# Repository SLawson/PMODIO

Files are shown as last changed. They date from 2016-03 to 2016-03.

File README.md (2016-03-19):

## PMODIO

#### Project Description
The PMODIO device is an IO expansion for use with the Digilent Nexys4DDR board. It has a 128x64 dot-matrix graphical display and a quadrature rotary encoder. It connects to to Nexys4DDR's expansion headers (JA & JB by default, but this can be configured).

This project contains a CadSoft EAGLE schematic and board layout, and bill of materials for constructing them from scratch. It also contains a Xilinx custom peripheral IP with drivers for interfacing with the board.

#### Repository Layout

	/doc
    	/datasheets						Third-party datasheets for all BOM components
        BOM.xlsx						Bill of materials
        PMODIO_DriverReference.pdf		PMODIO driver reference
        PMODIO_UserGuide.pdf			User guide for hardware and the peripheral
    /src
    	/doc							Documentation source files
        /function_test					Source code for a Vivado and Xilinx SDK project 
        								to verify breadboard/PCB functionality
                                        	- also provides driver usage examples
        /physical						Eagle schematic and board layout, solder stencil
        /PMODIO_1.0						Peripheral IP block
    /LICENSE							License description (GPL v3)
        
#### Repository Branches
 
| Branch Name 	|	Purpose 												|
|---|---|
| master	  	| release branch 											|
| rev1			| latest development for board revision 1.x					|
| dev			| development - will always correspond to latest board rev	|

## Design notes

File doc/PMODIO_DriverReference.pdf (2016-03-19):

## PMODIO

Generated by Doxygen 1.8.6

Fri Mar 18 2016 23:13:56

CONTENTS | 1

## Contents

1 Data Structure Index | 1
2 File Index | 2
3 Data Structure Documentation | 2
4 File Documentation | 3
Index | 25

## 1 Data Structure Index

Generated on Fri Mar 18 2016 23:13:56 for PMODIO by Doxygen

### 2 CONTENTS

### 1.1 Data Structures

Here are the data structures with brief descriptions:

LCD_pos | 2
PMODIO | 3

## 2 File Index

### 2.1 File List

Here is a list of all documented files with brief descriptions:

PMODIO.c | 3
PMODIO.h | 8
PMODIO_l.c | 14
PMODIO_l.h | 19

## 3 Data Structure Documentation

### 3.1 LCD_pos Struct Reference

#include <PMODIO.h>

Data Fields

- u8 x
- u8 y
- u8 page

### 3.1.1 Detailed Description

Tracks current LCD write position

### 3.1.2 Field Documentation

### 3.1.2.1 u8 LCD_pos::page

current page

### 3.1.2.2 u8 LCD_pos::x

current X coordinate

### 3.1.2.3 u8 LCD_pos::y

current Y coordinate

The documentation for this struct was generated from the following file:

- PMODIO.h

3.2 PMODIO Struct Reference | 3

### 3.2 PMODIO Struct Reference

#include <PMODIO.h>

Data Fields

- u32 base_addr
- LCD_pos current_pos
- u8 lcd_map [LCD_PAGES][LCD_COLS]

### 3.2.1 Detailed Description

One instance of this type must be instantiated for each instance of the PMODIO peripheral in the system

### 3.2.2 Field Documentation

### 3.2.2.1 u32 PMODIO::base_addr

device base address

### 3.2.2.2 LCD_pos PMODIO::current_pos

current LCD write position

### 3.2.2.3 u8 PMODIO::lcd_map[LCD_PAGES][LCD_COLS]

static array to track writes to LCD

The documentation for this struct was generated from the following file:

- PMODIO.h

## 4 File Documentation

### 4.1 PMODIO.c File Reference

#include "stdbool.h"

#include "xparameters.h"

#include "xil_types.h"

#include "xstatus.h"

#include "PMODIO.h"

#include "PMODIO_l.h"

Macros

- #define ROT_BTN_MSK 0x00000001
- #define ROT_CLR_SET_MSK 0x00000002
- #define ROT_CLR_CLR_MSK (ROT_CLR_SET_MSK ∧ 0xFFFFFFFF)
- #define SELF_TEST_REG_CNT 3
- #define SELF_TEST_PATTERN 0xF0F0F0F0

### 4 CONTENTS

Functions

- XStatus PMODIO_init (PMODIO ∗inst_p, u32 base_addr)
- XStatus PMODIO_selfTest (PMODIO ∗inst_p)
- XStatus PMODIO_ROT_setStep (PMODIO ∗inst_p, int step)
- XStatus PMODIO_ROT_setMaxCount (PMODIO ∗inst_p, int count)
- XStatus PMODIO_ROT_setMinCount (PMODIO ∗inst_p, int count)
- XStatus PMODIO_ROT_clr (PMODIO ∗inst_p)
- XStatus PMODIO_ROT_read (PMODIO ∗inst_p, int ∗rotary_cnt_p)
- bool PMODIO_ROT_isBtnPressed (PMODIO ∗inst_p)
- XStatus PMODIO_LCD_setPos (PMODIO ∗inst_p, u8 x, u8 y)
- LCD_pos PMODIO_LCD_getPos (PMODIO ∗inst_p)
- XStatus PMODIO_LCD_write (PMODIO ∗inst_p, u8 data, u8 mask)
- XStatus PMODIO_LCD_clr (PMODIO ∗inst_p)

### 4.1.1 Detailed Description

Author

Scott Lawson

Copyright

Scott Lawson, 2016

PMODIO peripheral driver API function implementations

The PMODIO peripheral interfaces with the PMODIO hardware, which consists of a KS0108-compatible 128 pixel x 64 pixel dot-matrix graphical LCD and a quadrature rotary encoder.

These functions allow an application to interface with the LCD and rotary encoder hardware to draw on the LCD and obtain the rotary encoder’s rotation count, and configure the rotary encoder’s step size per rotation, count limits, and rotation increment/decrement directions.

Note

The LCD code is derived from the GLCD library from microchip.com. Download link: http://www.-microchip.com/forums/download.axd?file=0;275906

Modification History:

Ver | Who | Date | Changes
1.0 | SRL | 16 Mar 2016 | Initial release

### 4.1.2 Macro Definition Documentation

4.1.2.1 #define ROT_BTN_MSK 0x00000001

rotary encoder pushbutton status

4.1.2.2 #define ROT_CLR_CLR_MSK (ROT_CLR_SET_MSK ∧ 0xFFFFFFFF)

clear count bit mask

4.1 PMODIO.c File Reference | 5

4.1.2.3 #define ROT_CLR_SET_MSK 0x00000002

set the clear count bit mask

4.1.2.4 #define SELF_TEST_PATTERN 0xF0F0F0F0

pattern written to registers and read back during self-test

4.1.2.5 #define SELF_TEST_REG_CNT 3

number of registers being tested

### 4.1.3 Function Documentation

### 4.1.3.1 XStatus PMODIO_init ( PMODIO ∗ inst_p, u32 base_addr )

Initializes the PMODIO peripheral

Configures rotary encoder defaults Count step is 1 Negative counts are allowed Max count of 2∧32

Parameters

inst_p | PMODIO instance address
base_addr | Base address of PMODIO instance

Returns

- XST_SUCCESS if all self-test code passed
- XST_FAILURE if any self-test code failed

Note

This must be the first function called for this peripheral
This function calls PMODIO_SelfTest(), so it’s notes apply for this function as well

### 4.1.3.2 XStatus PMODIO_LCD_clr ( PMODIO ∗ inst_p )

Clears all pixels on the LCD

Parameters

inst_p PMODIO instance address

Returns

XST_SUCESS

### 4.1.3.3 LCD_pos PMODIO_LCD_getPos ( PMODIO ∗ inst_p )

Retrieves the current LCD write position

Parameters

### 6 CONTENTS

inst_p PMODIO instance address

Returns

LCD_pos current write position of the LCD

### 4.1.3.4 XStatus PMODIO_LCD_setPos ( PMODIO ∗ inst_p, u8 x, u8 y )

Sets the X-Y position for the next data write

X coordinate valid range is 0 - 127, inclusive Y coordinate valid range is 0 - 63, inclusive

Parameters

inst_p | PMODIO instance address
x | x-coordinate
y | y-coordinate

Returns

- XST_SUCCESS if X and Y coordinates are in the valid range (x < 128 and Y < 64)
- XST_FAILURE if either coordinate is out of range

### 4.1.3.5 XStatus PMODIO_LCD_write ( PMODIO ∗ inst_p, u8 data, u8 mask )

Writes data to LCD at the current position

Parameters

inst_p | PMODIO instance address
data | data to write
mask | mask to select which bits are written

Returns

XST_SUCESS

Note

The PMODIO instance’s current X position will be automatically incremented by 1 on every write.
Since writes to the LCD must be done a full byte at a time, the mask argument is provided to prevent the caller from having to perform read-modify-write cycles when a data write overlaps with a previous write. The driver tracks all writes internally, and when writing new data, it handles the read-modify-write cyles to only write bits to the LCD that are enabled by a set bit in the mask.

### 4.1.3.6 XStatus PMODIO_ROT_clr ( PMODIO ∗ inst_p )

Resets the current count to zero

Parameters

inst_p PMODIO instance address

Returns

XST_SUCCESS

### 4.1.3.7 bool PMODIO_ROT_isBtnPressed ( PMODIO ∗ inst_p )

Returns the current state of the rotary encoder pushbutton

4.1 PMODIO.c File Reference | 7

Parameters

inst_p PMODIO instance address

Returns

true if the button is pressed, false otherwise

### 4.1.3.8 XStatus PMODIO_ROT_read ( PMODIO ∗ inst_p, int ∗ rotary_cnt_p )

Retrieves the current rotary encoder count

Parameters

inst_p | PMODIO instance address
rotary_cnt_p | pointer to the location to populate with the count

Returns

XST_SUCCESS

### 4.1.3.9 XStatus PMODIO_ROT_setMaxCount ( PMODIO ∗ inst_p, int count )

Sets the maximum count allowed

Parameters

inst_p | PMODIO instance address
count | the maximum allowed count

Returns

- XST_SUCCESS if max count input is valid (<= 2∧31 - 1)
- XST_FAILURE if count value is invalid

### 4.1.3.10 XStatus PMODIO_ROT_setMinCount ( PMODIO ∗ inst_p, int count )

Sets the minimum count allowed

Parameters

inst_p | PMODIO instance address
count | the maximum allowed count

Returns

- XST_SUCCESS if min count input is valid (>= -2∧31)
- XST_FAILURE if count value is invalid

### 4.1.3.11 XStatus PMODIO_ROT_setStep ( PMODIO ∗ inst_p, int step )

Sets the number that the rotary encoder count is incremented or decremented by per rotation

### 8 CONTENTS

Parameters

inst_p | PMODIO instance address
step | sets number of "counts" to increment or decrement the current count by when the ro-tary encoder is turned one click - can be negative to invert which rotation direction incre-ments/decrements the count

Returns

XST_SUCCESS

### 4.1.3.12 XStatus PMODIO_selfTest ( PMODIO ∗ inst_p )

Run a self-test on the driver/device

If the hardware system is not built correctly, this function may never return to the caller.

Parameters

inst_p PMODIO instance address

Returns

- XST_SUCCESS if all self-test code passed
- XST_FAILURE if any self-test code failed

Note

Caching must be turned off for this function to work
Self test may fail if data memory and device are not on the same bus

### 4.2 PMODIO.h File Reference

#include "stdbool.h"

Data Structures

- struct LCD_pos
- struct PMODIO

Macros

- #define ROT_CNT_ABS_MAX 2147483647
- #define ROT_CNT_ABS_MIN (-2147483648)
- #define LCD_X_MAX 127
- #define LCD_Y_MAX 63
- #define LCD_CHIP_ON 0x3F
- #define LCD_CHIP_OFF 0x3E
- #define LCD_DISP_START 0xC0
- #define LCD_COL_SET 0xB8
- #define LCD_ROW_SET 0x40
- #define LCD_COLS 128
- #define LCD_PAGES 8
- #define LCD_PAGE_HEIGHT 8

4.2 PMODIO.h File Reference | 9

Functions

- XStatus PMODIO_init (PMODIO ∗inst_p, u32 base_addr)
- XStatus PMODIO_selfTest (PMODIO ∗inst_p)
- XStatus PMODIO_ROT_setStep (PMODIO ∗inst_p, int step)
- XStatus PMODIO_ROT_setMaxCount (PMODIO ∗inst_p, int count)
- XStatus PMODIO_ROT_setMinCount (PMODIO ∗inst_p, int count)
- XStatus PMODIO_ROT_clr (PMODIO ∗inst_p)
- XStatus PMODIO_ROT_read (PMODIO ∗inst_p, int ∗rotary_cnt_p)
- bool PMODIO_ROT_isBtnPressed (PMODIO ∗inst_p)
- XStatus PMODIO_LCD_setPos (PMODIO ∗inst_p, u8 x, u8 y)
- XStatus PMODIO_LCD_write (PMODIO ∗inst_p, u8 data, u8 mask)
- XStatus PMODIO_LCD_clr (PMODIO ∗inst_p)
- LCD_pos PMODIO_LCD_getPos (PMODIO ∗inst_p)

### 4.2.1 Detailed Description

Author

Scott Lawson

Copyright

Scott Lawson, 2016

Header file for PMODIO driver API

Modification History:

Ver | Who | Date | Changes
1.0 | SRL | 16 Mar 2016 | Initial release

### 4.2.2 Macro Definition Documentation

4.2.2.1 #define LCD_CHIP_OFF 0x3E

LCD command bit pattern: chip off

4.2.2.2 #define LCD_CHIP_ON 0x3F

LCD command bit pattern: chip on

4.2.2.3 #define LCD_COL_SET 0xB8

LCD command bit pattern: column set

4.2.2.4 #define LCD_COLS 128

number of columns on the LCD

4.2.2.5 #define LCD_DISP_START 0xC0

LCD command bit pattern: display start

### 10 CONTENTS

4.2.2.6 #define LCD_PAGE_HEIGHT 8

pixel height of one page

4.2.2.7 #define LCD_PAGES 8

number of pages on the LCD

4.2.2.8 #define LCD_ROW_SET 0x40

LCD command bit pattern: row set

4.2.2.9 #define LCD_X_MAX 127

LCD maximum X coordinate

4.2.2.10 #define LCD_Y_MAX 63

LCD maximum y coordinate

4.2.2.11 #define ROT_CNT_ABS_MAX 2147483647

Rotary encoder absolute maximum count (2∧(32 - 1) - 1)

4.2.2.12 #define ROT_CNT_ABS_MIN (-2147483648)

Rotary encoder absolute minimum count (-2∧(32 - 1))

### 4.2.3 Function Documentation

### 4.2.3.1 XStatus PMODIO_init ( PMODIO ∗ inst_p, u32 base_addr )

Initializes the PMODIO peripheral

Configures rotary encoder defaults Count step is 1 Negative counts are allowed Max count of 2∧32

Parameters

inst_p | PMODIO instance address
base_addr | Base address of PMODIO instance

Returns

- XST_SUCCESS if all self-test code passed
- XST_FAILURE if any self-test code failed

Note

This must be the first function called for this peripheral
This function calls PMODIO_SelfTest(), so it’s notes apply for this function as well

### 4.2.3.2 XStatus PMODIO_LCD_clr ( PMODIO ∗ inst_p )

Clears all pixels on the LCD

4.2 PMODIO.h File Reference | 11

Parameters

inst_p PMODIO instance address

Returns

XST_SUCESS

### 4.2.3.3 LCD_pos PMODIO_LCD_getPos ( PMODIO ∗ inst_p )

Retrieves the current LCD write position

Parameters

inst_p PMODIO instance address

Returns

LCD_pos current write position of the LCD

### 4.2.3.4 XStatus PMODIO_LCD_setPos ( PMODIO ∗ inst_p, u8 x, u8 y )

Sets the X-Y position for the next data write

X coordinate valid range is 0 - 127, inclusive Y coordinate valid range is 0 - 63, inclusive

Parameters

inst_p | PMODIO instance address
x | x-coordinate
y | y-coordinate

Returns

- XST_SUCCESS if X and Y coordinates are in the valid range (x < 128 and Y < 64)
- XST_FAILURE if either coordinate is out of range

### 4.2.3.5 XStatus PMODIO_LCD_write ( PMODIO ∗ inst_p, u8 data, u8 mask )

Writes data to LCD at the current position

Parameters

inst_p | PMODIO instance address
data | data to write
mask | mask to select which bits are written

Returns

XST_SUCESS

Note

The PMODIO instance’s current X position will be automatically incremented by 1 on every write.
Since writes to the LCD must be done a full byte at a time, the mask argument is provided to prevent the caller from having to perform read-modify-write cycles when a data write overlaps with a previous write. The driver tracks all writes internally, and when writing new data, it handles the read-modify-write cyles to only write bits to the LCD that are enabled by a set bit in the mask.

### 12 CONTENTS

### 4.2.3.6 XStatus PMODIO_ROT_clr ( PMODIO ∗ inst_p )

Resets the current count to zero

4.2 PMODIO.h File Reference | 13

Parameters

inst_p PMODIO instance address

Returns

XST_SUCCESS

### 4.2.3.7 bool PMODIO_ROT_isBtnPressed ( PMODIO ∗ inst_p )

Returns the current state of the rotary encoder pushbutton

Parameters

inst_p PMODIO instance address

Returns

true if the button is pressed, false otherwise

### 4.2.3.8 XStatus PMODIO_ROT_read ( PMODIO ∗ inst_p, int ∗ rotary_cnt_p )

Retrieves the current rotary encoder count

Parameters

inst_p | PMODIO instance address
rotary_cnt_p | pointer to the location to populate with the count

Returns

XST_SUCCESS

### 4.2.3.9 XStatus PMODIO_ROT_setMaxCount ( PMODIO ∗ inst_p, int count )

Sets the maximum count allowed

Parameters

inst_p | PMODIO instance address
count | the maximum allowed count

Returns

- XST_SUCCESS if max count input is valid (<= 2∧31 - 1)
- XST_FAILURE if count value is invalid

### 4.2.3.10 XStatus PMODIO_ROT_setMinCount ( PMODIO ∗ inst_p, int count )

Sets the minimum count allowed

Parameters

### 14 CONTENTS

inst_p | PMODIO instance address
count | the maximum allowed count

Returns

- XST_SUCCESS if min count input is valid (>= -2∧31)
- XST_FAILURE if count value is invalid

### 4.2.3.11 XStatus PMODIO_ROT_setStep ( PMODIO ∗ inst_p, int step )

Sets the number that the rotary encoder count is incremented or decremented by per rotation

Parameters

inst_p | PMODIO instance address
step | sets number of "counts" to increment or decrement the current count by when the ro-tary encoder is turned one click - can be negative to invert which rotation direction incre-ments/decrements the count

Returns

XST_SUCCESS

### 4.2.3.12 XStatus PMODIO_selfTest ( PMODIO ∗ inst_p )

Run a self-test on the driver/device

If the hardware system is not built correctly, this function may never return to the caller.

Parameters

inst_p PMODIO instance address

Returns

- XST_SUCCESS if all self-test code passed
- XST_FAILURE if any self-test code failed

Note

Caching must be turned off for this function to work
Self test may fail if data memory and device are not on the same bus

### 4.3 PMODIO_l.c File Reference

#include "xil_types.h"

#include "xstatus.h"

#include "PMODIO.h"

#include "PMODIO_l.h"

4.3 PMODIO_l.c File Reference | 15

Macros

- #define LCD_SET_CNTL_RST_N 0x00000001
- #define LCD_SET_CNTL_EN_OP 0x00000002
- #define LCD_SET_CNTL_REG_SEL 0x00000004
- #define LCD_SET_CNTL_CS_1 0x00000008
- #define LCD_SET_CNTL_CS_2 0x00000010
- #define LCD_CLR_CNTL_RST_N (LCD_clear_CNTL_RST_N ∧ 0xFFFFFFFF)
- #define LCD_CLR_CNTL_EN_OP (LCD_clear_CNTL_EN_OP ∧ 0xFFFFFFFF)
- #define LCD_CLR_CNTL_REG_SEL (LCD_clear_CNTL_REG_SEL ∧ 0xFFFFFFFF)
- #define LCD_CLR_CNTL_CS_1 (LCD_clear_CNTL_CS_1 ∧ 0xFFFFFFFF)
- #define LCD_CLR_CNTL_CS_2 (LCD_SET_CNTL_CS_2 ∧ 0xFFFFFFFF)
- #define DELAY_LEN 600
- #define nop() __asm__ __volatile__ ("nop")

Functions

- XStatus PMODIO_LCD_init (PMODIO ∗inst_p)
- XStatus PMODIO_LCD_execCmd (PMODIO ∗inst_p, u8 cmd, LCD_CHIP chip)
- XStatus PMODIO_LCD_writeCommit (PMODIO ∗inst_p, u8 data)
- XStatus PMODIO_LCD_writeDataBits (PMODIO ∗inst_p, u8 pattern)
- XStatus PMODIO_LCD_clrCntlBit (PMODIO ∗inst_p, LCD_CNTL_BIT bit)
- XStatus PMODIO_LCD_setCntlBit (PMODIO ∗inst_p, LCD_CNTL_BIT bit)
- XStatus PMODIO_LCD_exec (PMODIO ∗inst_p)
- void PMODIO_LCD_delay ()

### 4.3.1 Detailed Description

Author

Scott Lawson

Copyright

Scott Lawson, 2016

Contains implementations of low-level driver functions. These functions are used by the driver API functions.

This code targets a KS0108-compatible, 128x64 pixel, graphical LCD. It supports the API functions to provide 8-bit pattern writing to arbitray positions on the LCD. For these LCDs, X is the long axis, and Y is the short axis. The display is split into Chip 1 for the left half, and Chip 2 for the right half. The display area is further split into eight rows of pixels (8 pixels tall each), called "pages."

Bit/Pin Mapping:

Abbreviation | Enum Name | Description
RST | RESET_N | Active-low reset
EN | EN_OP | Falling-edge triggered operation enable
RS | REG_SEL | Register select (0=instruction, 1=data)
CS1 | CS1 | Chip-select 1
CS2 | CS2 | Chip-select 2

### 16 CONTENTS

Implementation Note: For the current hardware revision, there weren’t enough pins available for every pin on the LCD interface, so the read/write pin was tied to ground, which sets it as write-only. Since we can’t read from the LCD memory, we can’t do read-write-modify cycles. This is a problem when the application layer wants to write new pixels in a page and column that already has some pixels, or perform a write that is spread across two pages. In both cases, previously written display data will be overwritten if the data byte is simply put on the data bus and written out.

This driver overcomes this limitation by maintaining its own 128-bit x 64-bit array to keep track of display data. Every write to the LCD is also reflected in this array, so read-modify-write cycles are performed using this array to avoid clobbering existing display data in the LCD. This array is maintained in the PMODIO structure that is allocated for each instance of the PMODIO peripheral in the Vivado block diagram (it’s the lcd_map attribute).

Warning

These functions are not intended to be used directly by any code except the PMODIO driver API functions. They may modify internal state or otherwise interfere with normal driver operation if called from the main application.

Note

This code is derived from the GLCD library from microchip.com. Download link: http://www.-microchip.com/forums/download.axd?file=0;275906

Modification History:

Ver | Who | Date | Changes
1.0 | SRL | 16 Mar 2016 | Initial release

### 4.3.2 Macro Definition Documentation

4.3.2.1 #define DELAY_LEN 600

sets number of iterations for nop() delay loop in PMODIO_LCD_exec

4.3.2.2 #define LCD_CLR_CNTL_CS_1 (LCD_clear_CNTL_CS_1 ∧ 0xFFFFFFFF)

LCD control pin clear mask: chip select 1

4.3.2.3 #define LCD_CLR_CNTL_CS_2 (LCD_SET_CNTL_CS_2 ∧ 0xFFFFFFFF)

LCD control pin clear mask: chip select 2

4.3.2.4 #define LCD_CLR_CNTL_EN_OP (LCD_clear_CNTL_EN_OP ∧ 0xFFFFFFFF)

LCD control pin clear mask: enable

4.3.2.5 #define LCD_CLR_CNTL_REG_SEL (LCD_clear_CNTL_REG_SEL ∧ 0xFFFFFFFF)

LCD control pin clear mask: register select

4.3.2.6 #define LCD_CLR_CNTL_RST_N (LCD_clear_CNTL_RST_N ∧ 0xFFFFFFFF)

LCD control pin clear mask: reset

4.3 PMODIO_l.c File Reference | 17

4.3.2.7 #define LCD_SET_CNTL_CS_1 0x00000008

LCD control pin set mask: chip select 1

4.3.2.8 #define LCD_SET_CNTL_CS_2 0x00000010

LCD control pin set mask: chip select 2

4.3.2.9 #define LCD_SET_CNTL_EN_OP 0x00000002

LCD control pin set mask: enable

4.3.2.10 #define LCD_SET_CNTL_REG_SEL 0x00000004

LCD control pin set mask: register select

4.3.2.11 #define LCD_SET_CNTL_RST_N 0x00000001

LCD control pin set mask: reset

4.3.2.12 #define nop( ) __asm__ __volatile__ ("nop")

Implements a Microblaze nop

Returns

NONE

Note

C-style signature: void nop()

### 4.3.3 Function Documentation

### 4.3.3.1 XStatus PMODIO_LCD_clrCntlBit ( PMODIO ∗ inst_p, LCD_CNTL_BIT bit )

Clears the specified LCD control bit without modifying others

Parameters

inst_p | PMODIO instance address
bit | bit to clear

Returns

XST_SUCCESS

### 4.3.3.2 void PMODIO_LCD_delay ( )

Executes a NOP loop to meet LCD timing requirements

Returns

NONE

### 4.3.3.3 XStatus PMODIO_LCD_exec ( PMODIO ∗ inst_p )

Instructs the LCD to act on the data/command on the data bus

The LCD uses the falling edge of the EN pin as an indicator that the data bus has data to be consumed. The RS pin indicates if the data bus contains an instruction (0) to be executed, or data (1) to be written to display ram. Delay no-op loops are used to meet the LCD timing requirements.

### 18 CONTENTS

Parameters

inst_p PMODIO instance address

Returns

XST_SUCCESS

### 4.3.3.4 XStatus PMODIO_LCD_execCmd ( PMODIO ∗ inst_p, u8 cmd, LCD_CHIP chip )

Writes a command to the specified LCD chip

Parameters

inst_p | PMODIO instance address
cmd | the command to execute
chip | the chip to execute the command for

Returns

XST_SUCCESS

Note

The LCD uses its 8-bit data bus both for data and for commands.

### 4.3.3.5 XStatus PMODIO_LCD_init ( PMODIO ∗ inst_p )

Initializes the LCD

Parameters

inst_p PMODIO instance address

Returns

XST_SUCCESS

### 4.3.3.6 XStatus PMODIO_LCD_setCntlBit ( PMODIO ∗ inst_p, LCD_CNTL_BIT bit )

Sets the specified LCD control bit without modifying others

Parameters

inst_p | PMODIO instance address
bit | bit to set

Returns

XST_SUCCESS

### 4.3.3.7 XStatus PMODIO_LCD_writeCommit ( PMODIO ∗ inst_p, u8 data )

Commits data to LCD display RAM and driver LCD map

4.4 PMODIO_l.h File Reference | 19

Parameters

inst_p | PMODIO instance address
data | data to write

Returns

XST_SUCESS

Note

The LCD’s current X position will be automatically incremented by 1 on every write.

### 4.3.3.8 XStatus PMODIO_LCD_writeDataBits ( PMODIO ∗ inst_p, u8 pattern )

Writes a specified pattern to the LCD data bus

Parameters

inst_p | PMODIO instance address
pattern | bit pattern to write to LCD data bus

Returns

XST_SUCCESS

Note

The LCD uses its 8-bit data bus both for data and for commands.

### 4.4 PMODIO_l.h File Reference

#include "PMODIO.h"

Macros

- #define ROT_CNT 0
- #define ROT_STEP 4
- #define ROT_STS 8
- #define ROT_MAX_CNT 12
- #define ROT_MIN_CNT 16
- #define ROT_RSVD0 20
- #define LCD_DATA 24
- #define LCD_CNTL 28
- #define LCD_RSVD0 32
- #define GP_RSVD0 36
- #define GP_RSVD1 40
- #define GP_RSVD2 44
- #define PMODIO_mWriteReg(BaseAddress, RegOffset, Data) Xil_Out32((BaseAddress) + (RegOffset), (u32)(Data))
- #define PMODIO_mReadReg(BaseAddress, RegOffset) Xil_In32((BaseAddress) + (RegOffset))

Typedefs

- typedef enum CNTL_BIT LCD_CNTL_BIT
- typedef enum CHIP LCD_CHIP

### 20 CONTENTS

Enumerations

- enum CNTL_BIT {
RESET_N, EN_OP, REG_SEL, CS1, CS2 }
- enum CHIP { CHIP1, CHIP2 }

Functions

- XStatus PMODIO_LCD_init (PMODIO ∗inst_p)
- XStatus PMODIO_LCD_execCmd (PMODIO ∗inst_p, u8 cmd, LCD_CHIP chip)
- XStatus PMODIO_LCD_writeDataBits (PMODIO ∗inst_p, u8 pattern)
- XStatus PMODIO_LCD_writeCommit (PMODIO ∗inst_p, u8 data)
- XStatus PMODIO_LCD_setCntlBit (PMODIO ∗inst_p, LCD_CNTL_BIT bit)
- XStatus PMODIO_LCD_clrCntlBit (PMODIO ∗inst_p, LCD_CNTL_BIT bit)
- XStatus PMODIO_LCD_exec (PMODIO ∗inst_p)
- void PMODIO_LCD_delay ()

### 4.4.1 Detailed Description

Author

Scott Lawson

Copyright

Scott Lawson, 2016

Header file for low-level driver functions in the PMODIO peripheral driver.

Warning

This file is only intended for PMODIO driver use, and should not be directly included by applications. Use PMODIO.h for API access.

Modification History:

Ver | Who | Date | Changes
1.0 | SRL | 16 Mar 2016 | Initial release

### 4.4.2 Macro Definition Documentation

4.4.2.1 #define GP_RSVD0 36

Register offset: General purpose reserved

4.4.2.2 #define GP_RSVD1 40

Register offset: General purpose reserved

4.4 PMODIO_l.h File Reference | 21

4.4.2.3 #define GP_RSVD2 44

Register offset: General purpose reserved

4.4.2.4 #define LCD_CNTL 28

Register offset: LCD control

4.4.2.5 #define LCD_DATA 24

Register offset: LCD data

4.4.2.6 #define LCD_RSVD0 32

Register offset: LCD reserved 0

4.4.2.7 #define PMODIO_mReadReg( BaseAddress, RegOffset ) Xil_In32((BaseAddress) + (RegOffset))

Read a value from a PMODIO register. A 32 bit read is performed. If the component is implemented in a smaller width, only the least significant data is read from the register. The most significant data will be read as 0.

Parameters

BaseAddress | is the base address of the PMODIO device.
RegOffset | is the register offset from the base to write to.

Returns

Data is the data from the register.

Note

C-style signature: u32 PMODIO_mReadReg(u32 BaseAddress, unsigned RegOffset)

4.4.2.8 #define PMODIO_mWriteReg( BaseAddress, RegOffset, Data ) Xil_Out32((BaseAddress) + (RegOffset), (u32)(Data))

Write a value to a PMODIO register. A 32 bit write is performed. If the component is implemented in a smaller width, only the least significant data is written.

Parameters

BaseAddress | is the base address of the PMODIOdevice.
RegOffset | is the register offset from the base to write to.
Data | is the data written to the register.

Returns

None.

Note

C-style signature: void PMODIO_mWriteReg(u32 BaseAddress, unsigned RegOffset, u32 Data)

4.4.2.9 #define ROT_CNT 0

Register offset: Rotary encoder count

4.4.2.10 #define ROT_MAX_CNT 12

Register offset: Rotary encoder maximum allowed count

### 22 CONTENTS

4.4.2.11 #define ROT_MIN_CNT 16

Register offset: Rotary encoder minimum allowed count

4.4.2.12 #define ROT_RSVD0 20

Register offset: Rotary encoder reserved 0

4.4.2.13 #define ROT_STEP 4

Register offset: Rotary encoder step size

4.4.2.14 #define ROT_STS 8

Register offset: Rotary encoder status

### 4.4.3 Typedef Documentation

### 4.4.3.1 typedef enum CHIP LCD_CHIP

Available LCD Chips

### 4.4.3.2 typedef enum CNTL_BIT LCD_CNTL_BIT

LCD Control Bits

### 4.4.4 Enumeration Type Documentation

### 4.4.4.1 enum CHIP

Available LCD Chips

Enumerator

CHIP1 Chip 1 (left)

CHIP2 Chip 2 (right)

### 4.4.4.2 enum CNTL_BIT

LCD Control Bits

Enumerator

RESET_N Active-low reset

EN_OP Falling edge triggered operation enable

REG_SEL Register select (0 = instruction, 1 = command)

CS1 Chip Select 1 (left)

CS2 Chip Select 2 (right)

### 4.4.5 Function Documentation

### 4.4.5.1 XStatus PMODIO_LCD_clrCntlBit ( PMODIO ∗ inst_p, LCD_CNTL_BIT bit )

Clears the specified LCD control bit without modifying others

4.4 PMODIO_l.h File Reference | 23

Parameters

inst_p | PMODIO instance address
bit | bit to clear

Returns

XST_SUCCESS

### 4.4.5.2 void PMODIO_LCD_delay ( )

Executes a NOP loop to meet LCD timing requirements

Returns

NONE

### 4.4.5.3 XStatus PMODIO_LCD_exec ( PMODIO ∗ inst_p )

Instructs the LCD to act on the data/command on the data bus

The LCD uses the falling edge of the EN pin as an indicator that the data bus has data to be consumed. The RS pin indicates if the data bus contains an instruction (0) to be executed, or data (1) to be written to display ram. Delay no-op loops are used to meet the LCD timing requirements.

Parameters

inst_p PMODIO instance address

Returns

XST_SUCCESS

### 4.4.5.4 XStatus PMODIO_LCD_execCmd ( PMODIO ∗ inst_p, u8 cmd, LCD_CHIP chip )

Writes a command to the specified LCD chip

Parameters

inst_p | PMODIO instance address
cmd | the command to execute
chip | the chip to execute the command for

Returns

XST_SUCCESS

Note

The LCD uses its 8-bit data bus both for data and for commands.

### 4.4.5.5 XStatus PMODIO_LCD_init ( PMODIO ∗ inst_p )

Initializes the LCD

### 24 CONTENTS

Parameters

inst_p PMODIO instance address

Returns

XST_SUCCESS

### 4.4.5.6 XStatus PMODIO_LCD_setCntlBit ( PMODIO ∗ inst_p, LCD_CNTL_BIT bit )

Sets the specified LCD control bit without modifying others

Parameters

inst_p | PMODIO instance address
bit | bit to set

Returns

XST_SUCCESS

### 4.4.5.7 XStatus PMODIO_LCD_writeCommit ( PMODIO ∗ inst_p, u8 data )

Commits data to LCD display RAM and driver LCD map

Parameters

inst_p | PMODIO instance address
data | data to write

Returns

XST_SUCESS

Note

The LCD’s current X position will be automatically incremented by 1 on every write.

### 4.4.5.8 XStatus PMODIO_LCD_writeDataBits ( PMODIO ∗ inst_p, u8 pattern )

Writes a specified pattern to the LCD data bus

Parameters

inst_p | PMODIO instance address
pattern | bit pattern to write to LCD data bus

Returns

XST_SUCCESS

Note

The LCD uses its 8-bit data bus both for data and for commands.

## Index

base_addr
PMODIO,
3

CHIP1
PMODIO_l.h, 22
CHIP2
PMODIO_l.h, 22
CS1
PMODIO_l.h, 22
CS2
PMODIO_l.h, 22
CHIP
PMODIO_l.h, 22
CNTL_BIT
PMODIO_l.h, 22
current_pos
PMODIO,
3

DELAY_LEN
PMODIO_l.c, 16

EN_OP
PMODIO_l.h, 22

GP_RSVD0
PMODIO_l.h, 20
GP_RSVD1
PMODIO_l.h, 20
GP_RSVD2
PMODIO_l.h, 20

LCD_CHIP
PMODIO_l.h, 22
LCD_CHIP_OFF
PMODIO.h,
9
LCD_CHIP_ON
PMODIO.h,
9
LCD_CNTL
PMODIO_l.h, 21
LCD_CNTL_BIT
PMODIO_l.h, 22
LCD_COL_SET
PMODIO.h,
9
LCD_COLS
PMODIO.h,
9
LCD_DATA
PMODIO_l.h, 21
LCD_DISP_START
PMODIO.h,
9
LCD_PAGE_HEIGHT
PMODIO.h,
9
LCD_PAGES
PMODIO.h, 10
LCD_ROW_SET
PMODIO.h, 10
LCD_RSVD0

PMODIO_l.h, 21
LCD_X_MAX
PMODIO.h, 10
LCD_Y_MAX
PMODIO.h, 10
LCD_pos,
2
page,

2
x,

2
y,

2
lcd_map
PMODIO,
3

nop
PMODIO_l.c, 17

PMODIO_l.h
CHIP1, 22
CHIP2, 22
CS1, 22
CS2, 22
EN_OP, 22
REG_SEL, 22
RESET_N, 22
PMODIO,
3
base_addr,
3
current_pos,

3
lcd_map,
3
PMODIO.c,
3
PMODIO_LCD_clr,
5
PMODIO_LCD_getPos,
5
PMODIO_LCD_setPos,
6
PMODIO_LCD_write,
6
PMODIO_ROT_clr,
6
PMODIO_ROT_isBtnPressed,
6
PMODIO_ROT_read,
7
PMODIO_ROT_setMaxCount,
7
PMODIO_ROT_setMinCount,
7
PMODIO_ROT_setStep,
7
PMODIO_init,
5
PMODIO_selfTest,
8
ROT_BTN_MSK,
4
PMODIO.h,
8
LCD_CHIP_OFF,
9
LCD_CHIP_ON,
9
LCD_COL_SET,
9
LCD_COLS,
9
LCD_DISP_START,
9
LCD_PAGES, 10
LCD_ROW_SET, 10
LCD_X_MAX, 10
LCD_Y_MAX, 10
PMODIO_LCD_clr, 10
PMODIO_LCD_getPos, 11
PMODIO_LCD_setPos, 11
PMODIO_LCD_write, 11
PMODIO_ROT_clr, 11

### 26 INDEX

PMODIO_ROT_isBtnPressed, 13
PMODIO_ROT_read, 13
PMODIO_ROT_setMaxCount, 13 PMODIO_ROT_setMinCount, 13 PMODIO_ROT_setStep, 14
PMODIO_init, 10
PMODIO_selfTest, 14
PMODIO_LCD_clr
PMODIO.c, 5
PMODIO.h, 10
PMODIO_LCD_clrCntlBit
PMODIO_l.c, 17
PMODIO_l.h, 22
PMODIO_LCD_delay
PMODIO_l.c, 17
PMODIO_l.h, 23
PMODIO_LCD_exec
PMODIO_l.c, 17
PMODIO_l.h, 23
PMODIO_LCD_execCmd
PMODIO_l.c, 18
PMODIO_l.h, 23
PMODIO_LCD_getPos
PMODIO.c, 5
PMODIO.h, 11
PMODIO_LCD_init
PMODIO_l.c, 18
PMODIO_l.h, 23
PMODIO_LCD_setCntlBit
PMODIO_l.c, 18
PMODIO_l.h, 24
PMODIO_LCD_setPos
PMODIO.c, 6
PMODIO.h, 11
PMODIO_LCD_write
PMODIO.c, 6
PMODIO.h, 11
PMODIO_LCD_writeCommit
PMODIO_l.c, 18
PMODIO_l.h, 24
PMODIO_LCD_writeDataBits
PMODIO_l.c, 19
PMODIO_l.h, 24
PMODIO_ROT_clr
PMODIO.c, 6
PMODIO.h, 11
PMODIO_ROT_isBtnPressed
PMODIO.c, 6
PMODIO.h, 13
PMODIO_ROT_read
PMODIO.c, 7
PMODIO.h, 13
PMODIO_ROT_setMaxCount
PMODIO.c, 7
PMODIO.h, 13
PMODIO_ROT_setMinCount
PMODIO.c, 7
PMODIO.h, 13

PMODIO_ROT_setStep
PMODIO.c, 7
PMODIO.h, 14
PMODIO_init
PMODIO.c, 5
PMODIO.h, 10
PMODIO_l.c, 14
DELAY_LEN, 16
nop, 17
PMODIO_LCD_delay, 17
PMODIO_LCD_exec, 17
PMODIO_LCD_execCmd, 18
PMODIO_LCD_init, 18
PMODIO_LCD_writeCommit, 18 PMODIO_l.h, 19
CHIP, 22
CNTL_BIT, 22
GP_RSVD0, 20
GP_RSVD1, 20
GP_RSVD2, 20
LCD_CHIP, 22
LCD_CNTL, 21
LCD_CNTL_BIT, 22
LCD_DATA, 21
LCD_RSVD0, 21
PMODIO_LCD_delay, 23
PMODIO_LCD_exec, 23
PMODIO_LCD_execCmd, 23
PMODIO_LCD_init, 23
PMODIO_LCD_writeCommit, 24 PMODIO_mReadReg, 21
PMODIO_mWriteReg, 21
ROT_CNT, 21
ROT_MAX_CNT, 21
ROT_MIN_CNT, 21
ROT_RSVD0, 22
ROT_STEP, 22
ROT_STS, 22
PMODIO_mReadReg
PMODIO_l.h, 21
PMODIO_mWriteReg
PMODIO_l.h, 21
PMODIO_selfTest
PMODIO.c, 8
PMODIO.h, 14
page
LCD_pos, 2

REG_SEL
PMODIO_l.h, 22
RESET_N
PMODIO_l.h, 22
ROT_BTN_MSK
PMODIO.c, 4
ROT_CLR_CLR_MSK
PMODIO.c, 4
ROT_CLR_SET_MSK
PMODIO.c, 4
ROT_CNT

INDEX | 27

PMODIO_l.h, 21
ROT_CNT_ABS_MAX
PMODIO.h, 10
ROT_CNT_ABS_MIN
PMODIO.h, 10
ROT_MAX_CNT
PMODIO_l.h, 21
ROT_MIN_CNT
PMODIO_l.h, 21
ROT_RSVD0
PMODIO_l.h, 22
ROT_STEP
PMODIO_l.h, 22
ROT_STS
PMODIO_l.h, 22

SELF_TEST_PATTERN
PMODIO.c, 5

x
LCD_pos, 2

y
LCD_pos, 2

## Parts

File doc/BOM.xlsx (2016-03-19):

PMODIO BOM
Item # | Description | Manufacturer | Digikey Part # | Cost (USD, Ea) | Quantity | Extended Cost (USD) | Notes
 | IO
1 | Display, LCD, 128x64 | Newhaven Display Intl | NHD-12864MZ-FSW-GBW-L-ND | $21.00 | 1 | $21.00
2 | Encoder, Rotary, Quadrature, w/ Pushbutton | Bourns Inc | PEC11R-4215K-S0012-ND | $1.68 | 1 | $1.68
 | IC
3 | Voltage Inverter, 2.7V-5.5V, LM2776 | Texas Instruments | 296-42300-1-ND | $1.27 | 1 | $1.27
4 | Booster, Charge Pump, 2.7V-5VI, 5VO, LTC1754ES6 | Linear Technology | LTC1754ES6-5#TRMPBFCT-ND | $3.46 | 1 | $3.46
5 | Bus Transceiver, 8Bit, 24TSSOP | Texas Instruments | 296-12183-1-ND | $1.02 | 2 | $2.04
 | Passive
6 | Resistor, SMD, 4.7kOhm, 0.1% Tol, 1/10W | Susumu | RG16P4.7KBCT-ND | $0.53 | 7 | $3.71
7 | Resistor, SMD, 2.2kOhm, 0.1% Tol, 1/10W | Susumu | RG16P2.2KBCT-ND | $0.53 | 1 | $0.53
8 | Capacitor, Ceramic, 1uF, 6.3v, X5R | TDK Corporation | 445-4998-1-ND | $0.10 | 2 | $0.20
9 | Capacitor, Ceramic, 2.2uF, 6.3v, X5R | TDK Corporation | 445-6847-1-ND | $0.20 | 2 | $0.40
10 | Capacitor, Ceramic, 10uF, 6.3v, X5R | Murata Electronics North America | 490-3340-1-ND | $0.15 | 2 | $0.30
 | Packaging
11 | Connection Header, Right Angle, Dual Row, 2.54MM Pitch, 12 Pin | Wurth Electronics Inc | 732-5354-ND | $0.86 | 2 | $1.72
12 | Connection Header, Straight, Single Row, 2MM Pitch, 20 Pin | 3M | 3M9334-ND | $1.25 | 1 | $1.25
13 | Bumper, Cylindrical, 0.374" Diameter, Clear | Essentra Components | RPC1620-ND | $0.38 | 4 | $1.52
14 | PCB | Osh Park | N/A | $13.88 | 1 | $13.88 | Must be ordered in sets of three
 | Total |  |  |  |  | $52.96

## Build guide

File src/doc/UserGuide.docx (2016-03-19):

# PMODIO User Guide

Revision 1.0

Date 19 March 2016

Author Scott Lawson

Notice: All trademarks are property of their respective owners.

# Table of Contents

# Revision History

Revision Number | Author | Date | Change Description
1.0 | SRL | 18-Mar-16 | Initial Release

# Overview

## Document Scope

This document is intended to provide detailed information about the design, implementation, and usage of both the PMODIO physical hardware and the PMODIO peripheral, including its drivers. It is intended to provide the reader an understanding of how the various components of the project work together and how to use them in a design.

This document assumes the reader is already familiar with the Xilinx™ Vivado Design Suite™, the Xilinx MicroBlaze™, and their usage of intellectual property (IP) blocks.

## Project Description

The Pmod Input/Output (PMODIO) project is intended to expand the capabilities of the Digilent™ Nexys 4 DDR (NX4) board by provided a rotary encoder and graphical liquid-crystal display (LCD) for use with its expansion headers. The PMODIO device is attached to the NX4 via the JA and JB expansion headers. Along with the physical PMODIO device, a peripheral intellectual property (IP) block is provided for instantiation in a Xilinx™ MicroBlaze™ (MB) design in Xilinx’s field programmable gate array (FPGA) development software, the Vivado Design Suite™. Additionally, drivers are provided to interface with the PMODIO IP block to control the device in a Xilinx SDK project.

## Conventions Used in this Document

Term | Refers to…
Physical Hardware | Physical PMODIO PCB and attached components
HDL Hardware | Verilog code in the IP block
Peripheral | PMODIO IP block for Xilinx Vivado and accompanying drivers

Table 1: Document Conventions

## Notes

- This project targets the Nexys 4 DDR, but may also work on the Nexys 4 if pin mappings are updated

# Physical Hardware Description

The PMODIO physical hardware consists primarily of a Newhaven Display Intl™ NHD-12864MZ-FSW-GBW-L 128x64 graphical LCD and a Bourns™ Inc PEC11R-4215K-S0012 quadrature rotary encoder. Various other components are also present to support voltage level shifting for the LCD, as it operates at 5v, and the NX4 operates at 3.3v. Physical hardware is connected as follows:

Figure 1: Physical Block Diagram

## LCD Detail

The LCD is a 128x64 graphical LCD with backlight. It utilizes a parallel data/control bus connected over a 20-pin header. Pin description:

Pin # | Symbol | Connection | Header Pin | Description
1 | VDD | 5.0v Power Supply | N/A | Power supply for logic
2 | VSS | Ground | N/A | Ground
3 | V0 | -3.3v Supply | N/A | Power supply for contrast
4-11 | DB0-DB7 | FPGA GPIO | JB10, JB4, JB9, JB3, JB8, JB2, JB7, JB1 | 8-bit data bus
12 | CS2B | FPGA GPIO | JA4 | Chip select, chip 2
13 | CS1B | FPGA GPIO | JA3 | Chip select, chip 1
14 | /RST | FPGA GPIO | JA2 | Active-low reset
15 | R/W | Ground | N/A | Read/write select (0=write, 1=read)
16 | RS | FPGA GPIO | JA7 | Register select (0=instruction, 1=data)
17 | E | FPGA GPIO | JA1 | Falling edge triggered operation enable
18 | VSS | Ground | N/A | Ground
19 | LED+ | 5.0v Power Supply | N/A | Power supply for LED backlight
20 | LED- | Ground | N/A | Ground for LED backlight

Table 2: LCD Pin Descriptions

### Pin Notes

#### Chip Selects

The LCD datasheet says that CS1B and CS2B are active-low, but they do not seem to behave this way. The PMDIO drivers treat them as if they are active-high.

#### R/W Pin

The R/W pin is grounded because between the rotary encoder and LCD, there were seventeen total signals that needed to fit in two NX4 expansion headers, but each header has eight data pins, for a total of only sixteen pins available. It was decided that read capability from the LCD was not necessary, so the R/W pin was grounded, permanently putting the LCD in write mode.

#### Data/Control Pins

All “FPGA GPIO” connected pins are actually connected to the output of the 8-bit transceivers shown in Figure 1 to shift the signals from 3.3v to the LCD’s operating voltage of 5.0v. (This does not apply to the FPGA GPIO pins for the rotary encoder below.)

## Rotary Encoder Detail

The rotary encoder is a contact-switched, quadrature rotary encoder with a pushbutton. Pin description:

Pin Name | Connection | Header Pin | Description
SW1 | 3.3v Power Supply | N/A | Pushbutton signal w/ pull-down
SW2 | FPGA GPIO | JA8 | Pushbutton supply
A | FPGA GPIO | JA10 | A output, w/ pull-up
B | FPGA GPIO | JA9 | B output, w/ pull-up
C | Ground | N/A | Common ground for A and B outputs

Table 3: Rotary Encoder Pin Description

# PMODIO Peripheral Description

The PMODIO peripheral is an AXI4_Lite compliant IP block that communicates with the MicroBlaze via memory-mapped registers, and uses external ports to connect to the LCD and rotary encoder:

Figure 2: PMODIO Interfaces

## Port Descriptions

Signal Name | Connection | I/O | Initial State | Description
pmodio_aclk | Clock | I | N/A | AXI Clock
pmodio_aresetn | Reset | I | N/A | AXI Reset, active-low
pmodio_* | AXI4_Lite Bus | N/A | N/A | AXI4_Lite Slave Interface signals - see Appendix A of the AXI Reference Guide (UG761) for AXI4-Lite signals
ROT_ENC_A, ROT_ENC_B | Rotary Encoder: A, Rotary Encoder: B | I | N/A | A and B signals from the rotary encoder
ROT_ENC_BTN | Rotary Encoder: Button | I | N/A | Rotary encoder pushbutton
LCD_DATA[7:0] | LCD: DB | O | 0x00 | LCD data bus
LCD_EN_OP | LCD: EN | O | 0x0 | LCD enable operation
LCD_RESET_N | LCD: /RST | O | 0x0 | LCD active-low reset
LCD_REG_SEL | LCD: RS | O | 0x0 | LCD register select
LCD_CS_1 | LCD: CS1B | O | 0x0 | LCD chip select 1
LCD_CS_2 | LCD: CS2B | O | 0x0 | LCD chip select 2

Table 4: PMODIO Port Descriptions

## PMODIO Peripheral Architecture

Figure 3: PMODIO Module Block Diagram

## Register Map

### Rotary Encoder Current Count Register (ROT_ENC_CNT_REG)

Offset: 0x00

Contains the current count output from the rotary encoder counter module. The value stored here is signed.

This register is read-only.

31 … 0

Current Signed Count

### Rotary Encoder Step Register (ROT_ENC_STEP_REG)

Offset: 0x04

Contains the value by which a single step of the rotary encoder will increment or decrement the count. The value stored here is signed. Due to the way the rotary encoder position is decoded, two clicks on the rotary encoder is one step. If the value here is positive, clockwise rotations will increment the count and counter-clockwise rotations will decrement the count. This behavior will be reversed if the value stored here is negative.

31 … 0

Step Size

### Rotary Encoder Status Register (ROT_ENC_STS_REG)

Offset: 0x08

Contains the rotary encoder status, which is currently only the pushbutton state.

Pushbutton State:

0 = Button not pushed

1 = Button pushed

ROT_ENC_STS_REG[0] is read-only.

31 … 0 | 0
Reserved | Button Status

### Rotary Encoder Maximum Count Register (ROT_ENC_MAX_CNT_REG)

Offset: 0x0C

Contains the maximum value the rotary encoder is allowed to count to, inclusive. The value stored here is signed.

Warning: setting this register to a value lower than ROT_ENC_MIN_CNT_REG results in undefined behavior.

31 … 0

Maximum Allowed Count

### Rotary Encoder Minimum Count Register (ROT_ENC_MIN_CNT_REG)

Offset: 0x10

Contains the minimum value the rotary encoder is allowed to count to, inclusive. The value stored here is signed.

Warning: setting this register to a value higher than ROT_ENC_MAX_CNT_REG results in undefined behavior.

31 … 0

Minimum Allowed Count

### Rotary Encoder Reserved Register 0 (ROT_RSVD0_REG)

Offset: 0x14

Reserved. Used for write/read test during self-test by driver.

31 … 0

Reserved

### LCD Data Register (LCD_DATA_REG)

Offset: 0x18

Wired directly to the LCD data bus ports. Register bit numbers correspond to data bus bit numbers. (Ex: LCD_DATA_REG[3] is connected to DB[3].)

31 … 08 | 7 | 6 | 5 | 4 | 3 | 2 | 1 | 0
Reserved | LCD Data Bus[7:0]

### LCD Control Register (LCD_CNTL_REG)

Offset: 0x1C

LCD_CNTL_REG[0:5] are wired directly to the LCD control pins. This register is used to assert and deassert pins on the LCD controller. Masks for accessing these pins are defined in PMODIO_l.h.

31 … 05 | 4 | 3 | 2 | 1 | 0
Reserved | CS2B | CS1B | RS | EN | /RST

### LCD Reserved Register 0 (LCD_RSVD0_REG)

Offset: 0x20

Reserved. Used for write/read test during self-test by driver.

31 … 0

Reserved

### General Purpose Reserved Registers (GP_RSVD0_REG, GP_RSVD1_REG, GP_RSVD2_REG)

Offset: 0x24, 0x28, 0x2C

Reserved. Used for write/read test during self-test by driver.

31 … 0

Reserved

## Driver Software

The driver source code is contained in the following files:

File Name | Description
PMODIO_l.c | Low-level driver code, only intended to be called by the high-level drivers
PMODIO_l.h | Low-level driver code header file, only intended to be included in other driver source files
PMODIO.c | High-level driver API function implementations
PMODIO.h | High-level driver API header file, intended to be included in MicroBlaze applications that use the PMODIO peripheral

Table 5: PMODIO Driver Files

### Rotary Encoder

The rotary encoder driver code is very simple, because all of the counting behavior is implemented in hardware. The driver is only responsible for reading count and button status from the registers, and setting count parameters by writing to the registers.

### LCD

The LCD driver is more complex, because it must resolve X-Y coordinates into column-page addresses in the regions that the LCD is divided into and handle writes to any location:

Figure 4: LCD Display Regions

At the driver API level, LCD write positions handled as simple X-Y coordinates for ease of use. When writing to the LCD, all writes must be page-aligned. Any non-page-aligned write actually causes two writes to the LCD to draw on both pages. Since writes are done a full byte at a time (bytes are written vertically, where DB[0] is written at the lowest Y coordinate), this introduces the possibility of overwriting previously written pixels. For example, a write at position (0, 4) means that DB[3:0] are written to column 0, page 0, while DB[7:4] are written to column 0, page 1. Without performing a read-modify-write (RMW) cycle, the currently displayed pixels at column 0, page 0[0:3] and column 0, page 1[4:7] will be overwritten. However, the RW pin on the LCD is tied low on the PCB, disabling reads.

The driver handles this case by maintaining a 1KB static array (128b x 64b = 1KB), where each bit corresponds to a pixel on the LCD. Every write to the LCD is also written to this array. When a write occurs that would clobber previously written bits, the bits that need to be retained are retrieved from the array and are combined with the new data with bit shifts and masks before being written both to the LCD and back to the array.

Note that the driver’s write data function that is available through its API has this signature:

PMODIO_LCD_write(PMODIO *inst_p, u8 data, u8 mask)

It accepts a mask argument in addition to the data bits to write. When a write to the LCD occurs, only the bits set in the mask argument will be written to the LCD. This allows per-pixel control over writes, preventing previously written data from being clobbered. If the mask is not 0xFF, even page-aligned writes will trigger a RMW cycle.

# Known Issues

1) Noisy rotary encoder

https://github.com/SLawson/PMODIO/issues/1

2) Rotary encoder doesn’t obey non-negative minimum counts

https://github.com/SLawson/PMODIO/issues/2

3) Incorrect xparamsters.h base addresses

https://github.com/SLawson/PMODIO/issues/2

See GitHub bug tracker for more details: https://github.com/SLawson/PMODIO/issues

# Resources

## Product Links

Digilent Nexys 4 DDR

http://store.digilentinc.com/nexys-4-ddr-artix-7-fpga-trainer-board-recommended-for-ece-curriculum/

Newhaven Display NHD-12864MZ-FSW-GBW-L

http://www.newhavendisplay.com/nhd12864mzfswgbwl-p-492.html

Bourns Inc PEC11R-4215K-S0012

http://www.bourns.com/docs/Product-Datasheets/PEC11R.pdf?sfvrsn=3

## Reference Documents

AXI Reference Guide

http://www.xilinx.com/support/documentation/ip_documentation/ug761_axi_reference_guide.pdf

NT7108 Application Notes (LCD Controller)

http://www.newhavendisplay.com/app_notes/NT7108.pdf

PMODIO User Guide Revision 1.0 ii

PMODIO User Guide Revision 1.0 Page 12

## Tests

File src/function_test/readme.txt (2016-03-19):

PMODIO Function Test

The purpose of these files is to:

    A) Provide the basis for Xilinx Vivado and SDK projects that can check the functionality of a
       PMODIO breadboard or PCB

    B) Provide initialization and usage examples for the PMDIO driver

Included:

    pmodio_top_level.v:

        Top-level Verilog module for the Vivado function test project.  The block diagram should be
        named "system" and have a PMODIO peripheral instantiated in it, attached to a MicroBlaze via
        the AXI4_Lite bus. The peripheral's ports should be mapped externally. See source for expected
        port names.

    pmodio_function_test.xdc:

        Stub contraints files with appropriate pin mappings for a PMODIO hardware device to be
        attached to the Nexys4DDR JA and JB headers, as well as system clock generation and LED
        mappings.

    pmodio_function_test.c:

        C source file for a function test SDK project. If the PMODIO hardware is set up correctly
        and the PMODIO peripheral is configured correctly, this program will illuminate the LCD in a
        checkerboard pattern. The LEDs will display the current rotary encoder count in binary, and
        the count will be reset to zero when the rotary encoder button is pressed, clearing the
        LEDs.

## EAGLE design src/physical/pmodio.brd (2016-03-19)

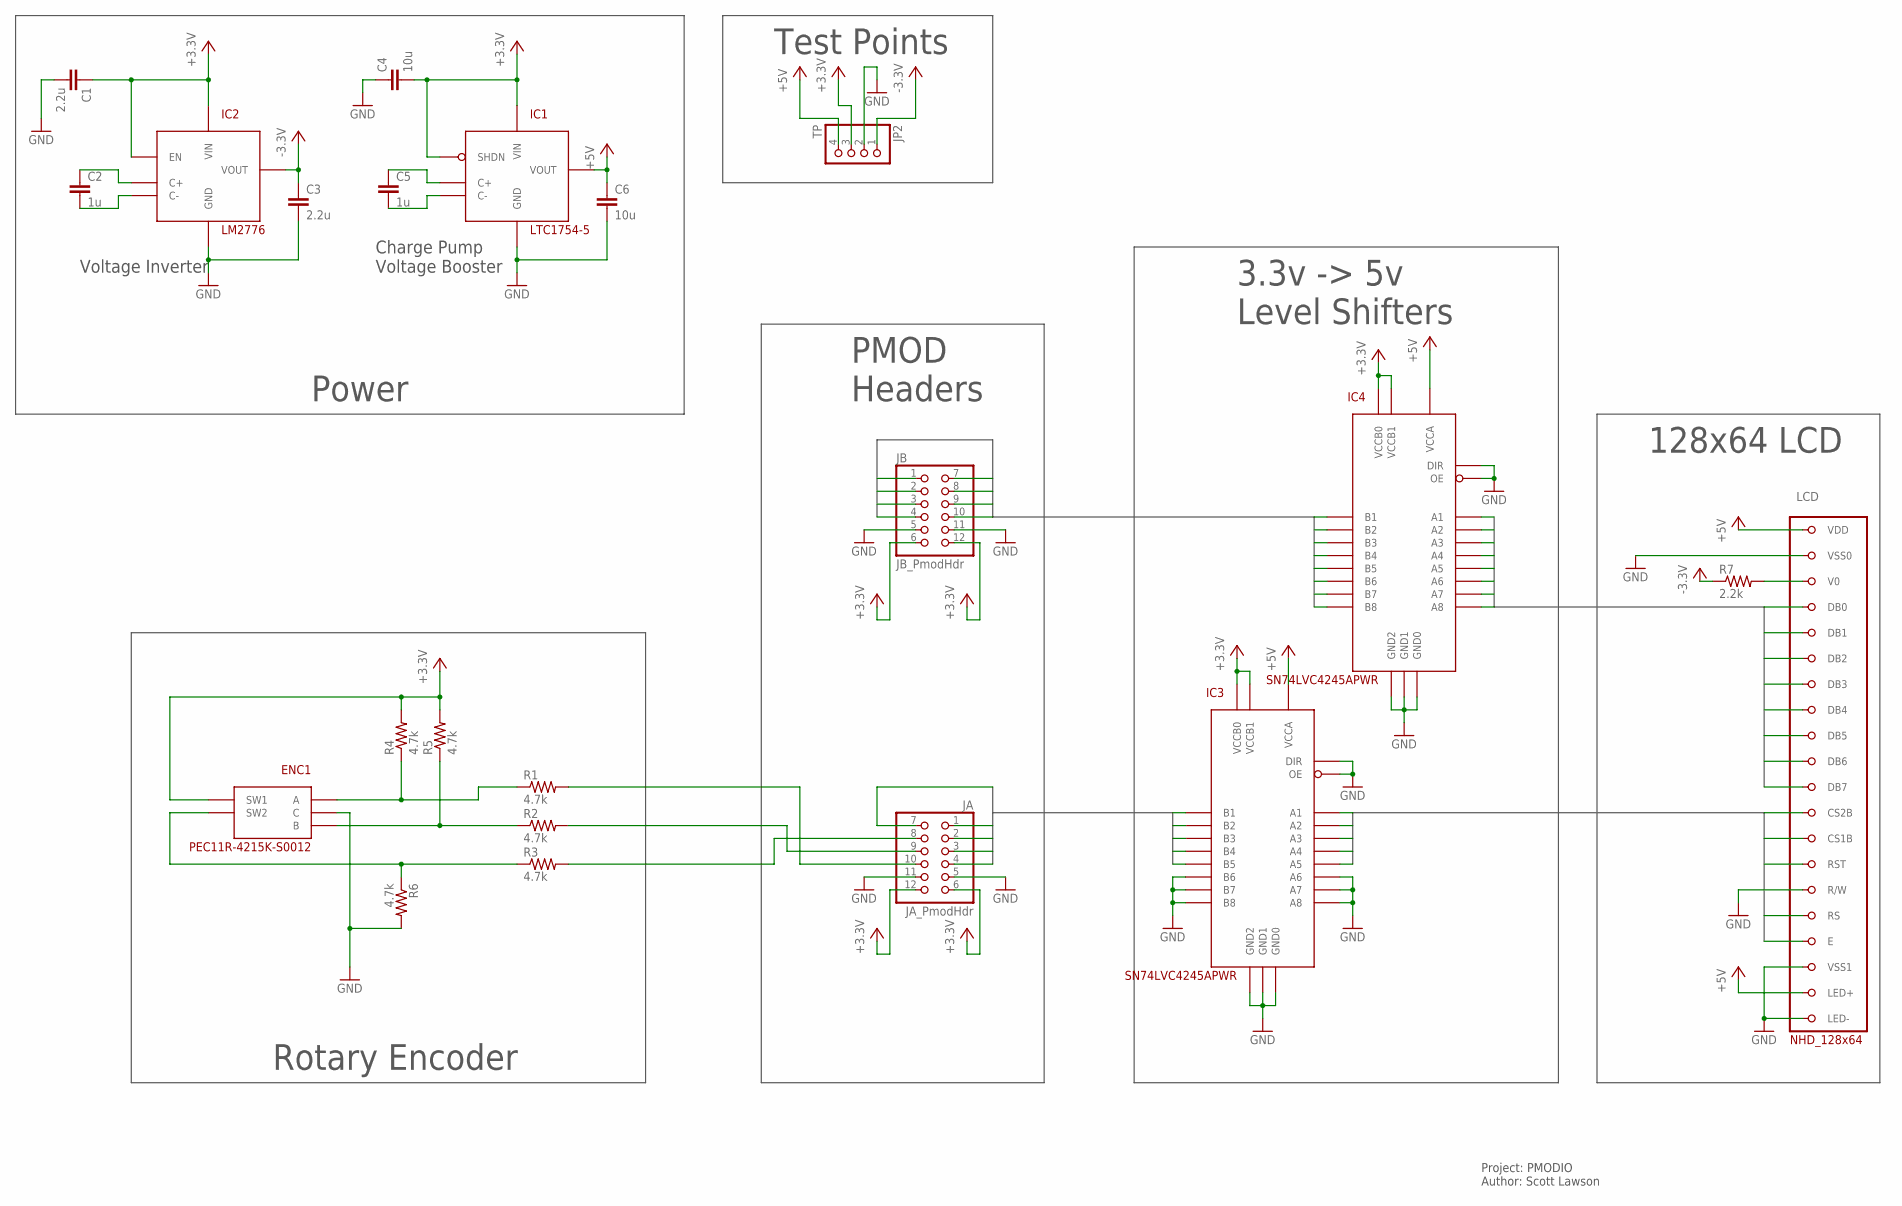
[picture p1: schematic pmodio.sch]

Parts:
C1, C3: 2.2u; C0402
C2, C5: 1u; C0402
C4, C6: 10u; C0805
ENC1: PEC11R-4215K-S0012; PEC11R-4XXXF-SXXXX
IC1: LTC1754-5; SOT23-6
IC2: LM2776; SOT23-6
IC3, IC4: SN74LVC4245APWR; TSSOP24
JA: JA_PmodHdr; 2X06/90
JB: JB_PmodHdr; 2X06/90
JP2: TP; 1X04
LCD: NHD_128x64; NHD-12864MZ-FSW-GBW-L
R1, R2, R3, R4, R5, R6: 4.7k; R0603
R7: 2.2k; R0603

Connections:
+3.3V: C1.1, C4.2, ENC1.SW1, IC1.3 (SHDN), IC1.5 (VIN), IC2.3 (VIN), IC2.4 (EN), IC3.23 (VCCB0), IC3.24 (VCCB1), IC4.23 (VCCB0), IC4.24 (VCCB1), JA.6, JA.12, JB.6, JB.12, JP2.3, R4.2, R5.2
+5V: C6.1, IC1.1 (VOUT), IC3.1 (VCCA), IC4.1 (VCCA), JP2.4, LCD.LED+, LCD.VDD
-3.3V: C3.1, IC2.1 (VOUT), JP2.1, R7.1
CNTLB_3.3V0: IC3.21 (B1), JA.4
CNTLB_3.3V1: IC3.20 (B2), JA.3
CNTLB_3.3V2: IC3.19 (B3), JA.2
CNTLB_3.3V3: IC3.18 (B4), JA.7
CNTLB_3.3V4: IC3.17 (B5), JA.1
CNTLB_5V0: IC3.3 (A1), LCD.CS2B
CNTLB_5V1: IC3.4 (A2), LCD.CS1B
CNTLB_5V2: IC3.5 (A3), LCD.RST
CNTLB_5V3: IC3.6 (A4), LCD.RS
CNTLB_5V4: IC3.7 (A5), LCD.E
DB_3.3V0: IC4.21 (B1), JB.10
DB_3.3V1: IC4.20 (B2), JB.4
DB_3.3V2: IC4.19 (B3), JB.9
DB_3.3V3: IC4.18 (B4), JB.3
DB_3.3V4: IC4.17 (B5), JB.8
DB_3.3V5: IC4.16 (B6), JB.2
DB_3.3V6: IC4.15 (B7), JB.7
DB_3.3V7: IC4.14 (B8), JB.1
DB_5V0: IC4.3 (A1), LCD.DB0
DB_5V1: IC4.4 (A2), LCD.DB1
DB_5V2: IC4.5 (A3), LCD.DB2
DB_5V3: IC4.6 (A4), LCD.DB3
DB_5V4: IC4.7 (A5), LCD.DB4
DB_5V5: IC4.8 (A6), LCD.DB5
DB_5V6: IC4.9 (A7), LCD.DB6
DB_5V7: IC4.10 (A8), LCD.DB7
GND: C1.2, C3.2, C4.1, C6.2, ENC1.C, IC1.2 (GND), IC2.2 (GND), IC3.2 (DIR), IC3.8 (A6), IC3.9 (A7), IC3.10 (A8), IC3.11 (GND0), IC3.12 (GND1), IC3.13 (GND2), IC3.14 (B8), IC3.15 (B7), IC3.16 (B6), IC3.22 (OE), IC4.2 (DIR), IC4.11 (GND0), IC4.12 (GND1), IC4.13 (GND2), IC4.22 (OE), JA.5, JA.11, JB.5, JB.11, JP2.2, LCD.LED-, LCD.RW (R/W), LCD.VSS0, LCD.VSS1, R6.2
unnamed: LCD.V0, R7.2
unnamed: C2.1, IC2.5 (C+)
unnamed: C2.2, IC2.6 (C-)
unnamed: C5.1, IC1.6 (C+)
unnamed: C5.2, IC1.4 (C-)
unnamed: ENC1.A, R1.1, R4.1
unnamed: ENC1.B, R2.1, R5.1
unnamed: ENC1.SW2, R3.1, R6.1
unnamed: JA.10, R1.2
unnamed: JA.8, R3.2
unnamed: JA.9, R2.2

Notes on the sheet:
Project: PMODIO Author: Scott Lawson
Voltage Inverter
Charge Pump Voltage Booster
Power
128x64 LCD
3.3v -> 5v Level Shifters
PMOD Headers
Rotary Encoder
Test Points

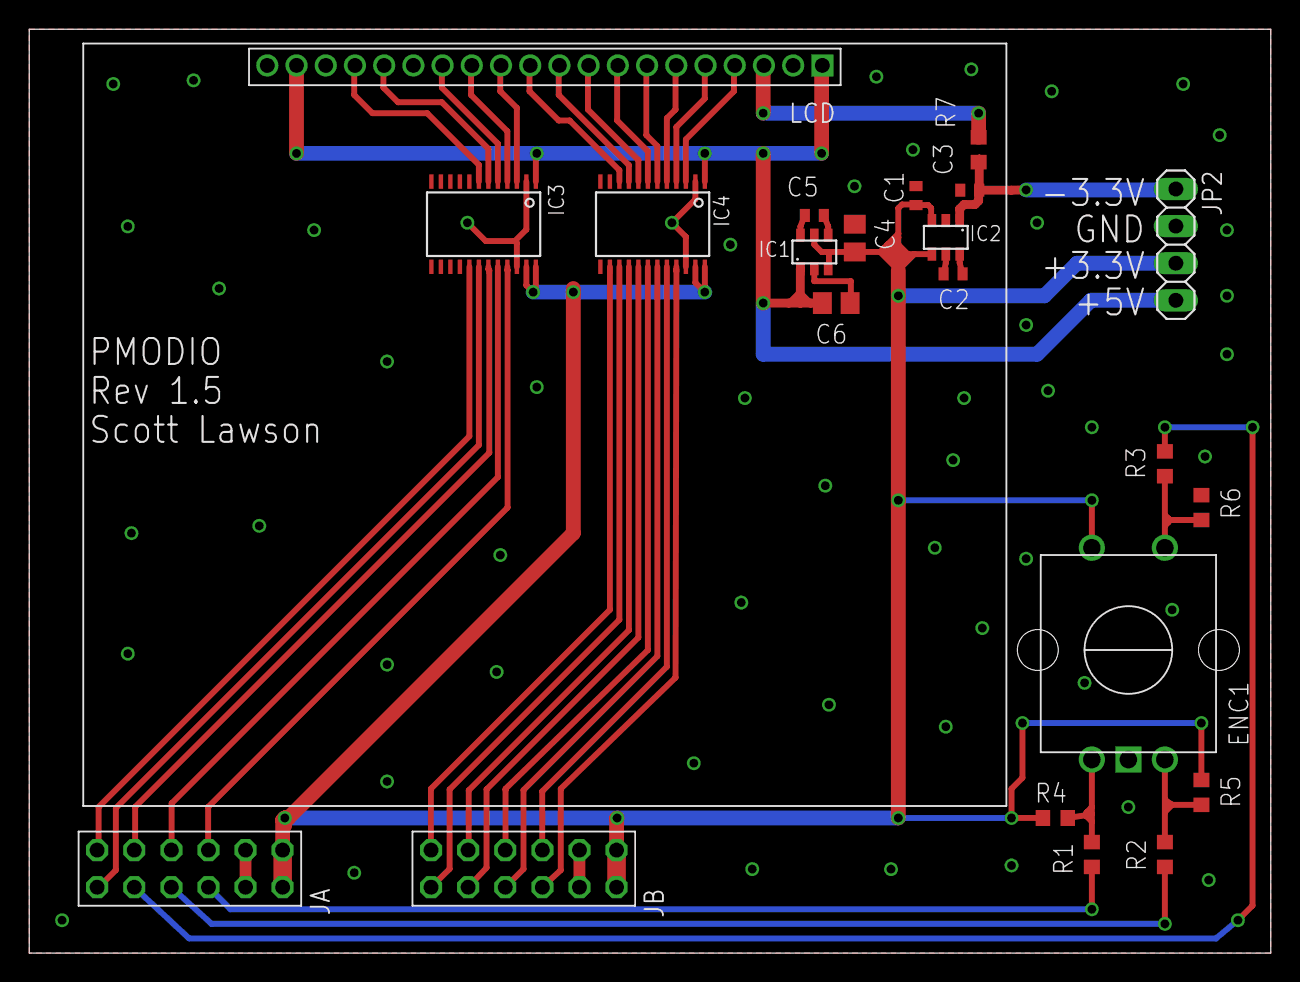
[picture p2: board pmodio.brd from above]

Board: 2 copper layers, 85.0 x 63.2 mm, 22 parts (0 on the bottom side), 41 nets.

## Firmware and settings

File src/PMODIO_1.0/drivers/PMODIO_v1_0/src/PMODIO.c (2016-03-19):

/*****************************************************************************/
/**
 * @file PMODIO.c
 *
 * @author      Scott Lawson
 * @copyright   Scott Lawson, 2016
 *
 * PMODIO peripheral driver API function implementations
 *
 * The PMODIO peripheral interfaces with the PMODIO hardware, which consists of
 * a KS0108-compatible 128 pixel x 64 pixel dot-matrix graphical LCD and a
 * quadrature rotary encoder.
 *
 * These functions allow an application to interface with the LCD and rotary
 * encoder hardware to draw on the LCD and obtain the rotary encoder's rotation
 * count, and configure the rotary encoder's step size per rotation, count
 * limits, and rotation increment/decrement directions.
 *
 * @note The LCD code is derived from the GLCD library from microchip.com.
 * Download link: http://www.microchip.com/forums/download.axd?file=0;275906
 *
 * <pre>
 *
 * Modification History:
 *
 * Ver      Who     Date            Changes
 *
 * 1.0      SRL     16 Mar 2016     Initial release
 *
 * </pre>
 *****************************************************************************/

/******************************************************************************
 *  Include Files 
 *****************************************************************************/

#include "stdbool.h"

#include "xparameters.h"
#include "xil_types.h"
#include "xstatus.h"

#include "PMODIO.h"
#include "PMODIO_l.h"

/******************************************************************************
 *  Constant Definitions 
 *****************************************************************************/

/* Rotary Encoder */

/** rotary encoder pushbutton status */
#define ROT_BTN_MSK     0x00000001  
/** set the clear count bit mask     */
#define ROT_CLR_SET_MSK 0x00000002  
/** clear count bit mask */
#define ROT_CLR_CLR_MSK (ROT_CLR_SET_MSK ^ 0xFFFFFFFF)  

/* Self Test*/

/** number of registers being tested */
#define SELF_TEST_REG_CNT   3   
/** pattern written to registers and read back during self-test      */
#define SELF_TEST_PATTERN   0xF0F0F0F0  

/******************************************************************************
 *  Function Definitions 
 *****************************************************************************/

/****************************** Initialization *******************************/

/**
 * Initializes the PMODIO peripheral
 *
 * Configures rotary encoder defaults
 *      Count step is 1
 *      Negative counts are allowed
 *      Max count of 2^32
 *
 * @param   inst_p      PMODIO instance address
 * @param   base_addr   Base address of PMODIO instance
 *
 * @return
 *
 *    - XST_SUCCESS   if all self-test code passed
 *    - XST_FAILURE   if any self-test code failed
 *
 * @note    This must be the first function called for this peripheral
 * @note    This function calls PMODIO_SelfTest(), so it's notes apply for this
 * function as well
 */
XStatus PMODIO_init(PMODIO *inst_p, u32 base_addr)
{

	inst_p->base_addr = base_addr;

    if (PMODIO_selfTest(inst_p) != XST_SUCCESS)
        return XST_FAILURE;

    PMODIO_ROT_setMinCount(inst_p, ROT_CNT_ABS_MIN);
    PMODIO_ROT_setMaxCount(inst_p, ROT_CNT_ABS_MAX);
    PMODIO_ROT_setStep(inst_p, 1);

    PMODIO_LCD_init(inst_p);

	return XST_SUCCESS;
}

/**
 * Run a self-test on the driver/device
 *
 * If the hardware system is not built correctly, this function may never
 * return to the caller.
 *
 * @param   inst_p      PMODIO instance address
 *
 * @return
 *
 *    - XST_SUCCESS   if all self-test code passed
 *    - XST_FAILURE   if any self-test code failed
 *
 * @note    Caching must be turned off for this function to work
 * @note    Self test may fail if data memory and device are not on the same bus
 */
XStatus PMODIO_selfTest(PMODIO *inst_p)
{
    /* registers to test */
    u32 target_regs [SELF_TEST_REG_CNT] = {ROT_RSVD0, LCD_RSVD0, GP_RSVD0};
    u32 base_addr = inst_p->base_addr;  
    u32 i;                             

    for (i=0; i<SELF_TEST_REG_CNT; ++i){

        /* write pattern */
        PMODIO_mWriteReg(base_addr, target_regs[i], SELF_TEST_PATTERN);

        /* read pattern back, bail if it doesn't match written pattern */
        if (PMODIO_mReadReg(base_addr, target_regs[i]) != SELF_TEST_PATTERN){

            return XST_FAILURE;
        }
        else{
            
            /* clear test pattern if read was successfull */
            PMODIO_mWriteReg(base_addr, target_regs[i], 0x0);
        }
    }

	return XST_SUCCESS;
}

/****************************** Rotary Encoder *******************************/

/**
 * Sets the number that the rotary encoder count is incremented or decremented by per rotation
 *
 *
 * @param   inst_p      PMODIO instance address
 * @param   step        sets number of "counts" to increment or decrement the
 * current count by when the rotary encoder is turned one click - can be
 * negative to invert which rotation direction increments/decrements the count
 *
 * @return  XST_SUCCESS
 */
XStatus PMODIO_ROT_setStep(PMODIO *inst_p, int step)
{

    PMODIO_mWriteReg(inst_p->base_addr, ROT_STEP, step);
    return XST_SUCCESS;
}

/**
 * Sets the maximum count allowed
 *
 * @param   inst_p      PMODIO instance address
 * @param   count       the maximum allowed count
 *
 * @return
 *
 *    - XST_SUCCESS   if max count input is valid (<= 2^31 - 1)
 *    - XST_FAILURE   if count value is invalid
 */
XStatus PMODIO_ROT_setMaxCount(PMODIO *inst_p, int count)
{

    if (count > ROT_CNT_ABS_MAX)
        return XST_FAILURE;

    PMODIO_mWriteReg(inst_p->base_addr, ROT_MAX_CNT, count);
    return XST_SUCCESS;
}

/**
 * Sets the minimum count allowed
 *
 * @param   inst_p      PMODIO instance address
 * @param   count       the maximum allowed count
 *
 * @return
 *
 *    - XST_SUCCESS   if min count input is valid (>= -2^31)
 *    - XST_FAILURE   if count value is invalid
 */
XStatus PMODIO_ROT_setMinCount(PMODIO *inst_p, int count)
{

    if (count < ROT_CNT_ABS_MIN)
        return XST_FAILURE;

    PMODIO_mWriteReg(inst_p->base_addr, ROT_MIN_CNT, count);
    return XST_SUCCESS;
}

/**
 * Resets the current count to zero
 *
 * @param   inst_p      PMODIO instance address
 *
 * @return  XST_SUCCESS
 */
XStatus PMODIO_ROT_clr(PMODIO *inst_p)
{
    u32 sts_reg;
    u32 base_addr = inst_p->base_addr;

    /* performs a read-write-modify cycle on the status register of the rotary
     * encoder to clear the count */
    sts_reg = PMODIO_mReadReg(base_addr, ROT_STS) | ROT_CLR_SET_MSK;
    PMODIO_mWriteReg(base_addr, ROT_STS, sts_reg);
    sts_reg &= ROT_CLR_CLR_MSK;
    PMODIO_mWriteReg(base_addr, ROT_STS, sts_reg);

    return XST_SUCCESS;
}
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

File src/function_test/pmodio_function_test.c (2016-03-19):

/*****************************************************************************/
/**
 * @file 		pmodio_function_test.c
 *
 * @author		Scott Lawson
 * @copyright	Scott Lawson, 2016
 *
 * This file serves two purposes:
 * 		1. Serve as an example of how to utilize the PMODIO peripheral in a
 * 			MicroBlaze system.
 * 		2. Provide a program to quickly test the connectivity and
 * 			functionality of a newly assembled PMODIO board.
 *
 * When this program is run in a MicroBlaze system with a PMODIO peripheral
 * and a PMODIO board attached to the Nexys4DDR, the LCD should illuminate
 * with a checkerboard pattern, and the rotary encoder should behave in the
 * following manner:
 *
 * 	- The current rotary encoder count is displayed on the 16 LEDs of the
 * 		Nexys4DDR in binary, where the LED[0] is the LSB.
 * 	- Rotating counterclockwise increments the count by two up to a maximum
 * 		of 32 (base 10).
 * 	- Rotating clockwise decrements the count by two, down to a minimum of
 * 		-32 (base 10).
 * 	- Pushing the rotary encoder pushbutton resets the count to zero.
 *
 * If both the LCD and rotary encoder behave as described, then the hardware
 * assembly and pin mappings are correct.
 *
 * <pre>
 * MODIFICATION HISTORY:
 *
 * Ver   	Who		Date     		Changes
 *
 * 1.0		srl		16 Mar 2016		Initial release
 *
 * </pre>
 *****************************************************************************/

/******************************************************************************
 *	Include Files
 *****************************************************************************/

#include "xparameters.h"
#include "xgpio.h"

#include "PMODIO.h"

/******************************************************************************
 *	Constant Definitions
 *****************************************************************************/

/* LED GPIO */
#define LED_GPIO_BASE_ADDR		XPAR_LED_GPIO_BASEADDR
#define LED_GPIO_DEVICE_ID		XPAR_LED_GPIO_DEVICE_ID

/* PMODIO Peripheral */
#define PMODIO_BASEADDR			XPAR_PMODIO_PMODIO_BASEADDR

/******************************************************************************
 *	Variable Definitions
 *****************************************************************************/

static XGpio LED_gpio;
static PMODIO pmodio_inst;

/******************************************************************************
 *	Main
 *****************************************************************************/
int main(){

	u8 x, y;			/* coordinates on the LCD */
	int rotary_count;	/* current rotary encoder count */

	/* initialize the PMODIO peripheral*/
	PMODIO_init(&pmodio_inst, PMODIO_BASEADDR);

	/* Initialize LED GPIO */
	XGpio_Initialize(&LED_gpio, LED_GPIO_DEVICE_ID);
	XGpio_SetDataDirection(&LED_gpio, 1, 0x0);

	/* Configure rotary encoder */
	PMODIO_ROT_setMaxCount(&pmodio_inst, 32);	/* set upper count limit */
	PMODIO_ROT_setMinCount(&pmodio_inst, -32);	/* set lower count limit */

	/* set step size - note the negative: this flips the default
	 * increment/decrement rotation directions, so clockwise rotation now
	 * decreases the count */
	PMODIO_ROT_setStep(&pmodio_inst, -2);

	/* creates a checkerboard pattern of 8x8 squares on the LCD */
	for (y=0; y<64; y+=8){

		PMODIO_LCD_setPos(&pmodio_inst, 0, y);

		for (x=0; x<128; ++x){

			if (((x & 0x08) && !(y & 0x08)) || (!(x & 0x08) && (y & 0x08))){
				PMODIO_LCD_write(&pmodio_inst, 0x00, 0xFF);
			}
			else{
				PMODIO_LCD_write(&pmodio_inst, 0xFF, 0xFF);
			}
		}
	}


	/* infinite loop polling the rotary count and updating the LEDs */
	while (1){

        PMODIO_ROT_read(&pmodio_inst, &rotary_count); /* get current count */

        /* reset the count to zero if the button is pressed */
        if (PMODIO_ROT_isBtnPressed(&pmodio_inst)){
        	PMODIO_ROT_clr(&pmodio_inst);
        }

        XGpio_DiscreteWrite(&LED_gpio, 1, rotary_count); /* update LEDs */
	}

	return (0);
}

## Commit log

2016-03-19 doc/: Initial push of documentation
    [BOM.xlsx]
2016-03-19 src/physical: Initial push of board sources
    [pmodio.brd, pmodio.sch]
